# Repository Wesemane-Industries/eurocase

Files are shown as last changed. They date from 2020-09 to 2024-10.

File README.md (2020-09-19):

# Eurocase
DIY Eurorack / Modular synthesizer case by Wesemane Industries

## Overview
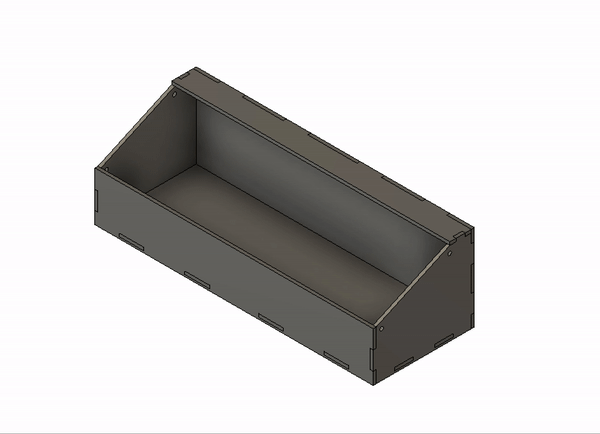
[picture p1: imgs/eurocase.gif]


## What you will need
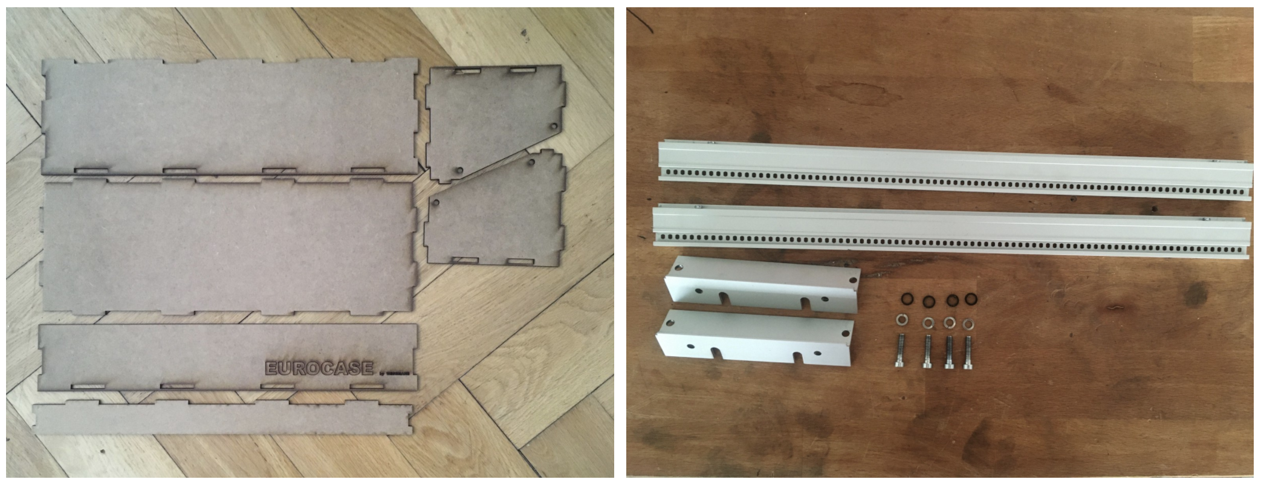
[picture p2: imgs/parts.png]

The left image shows all medium-density fibreboard (MDF) parts needed. You can either order them from my [Tindie shop](https://www.tindie.com/products/wesemane-industries/eurocase-by-wesemane-industries/) or laser cut them yourself (see DIY section below if you want to do so). <br>
The right image shows rails (including tapped strips), fixing brackets and all needed screws. You can get these parts from Schneidersladen following these links (Screws are included):<br>
* 2x [SB Rail 19"](https://schneidersladen.de/de/sb-rail-19-mit-kante)<br>
* 2x [Tapped strips 84TE (Gewindestreifen)](https://schneidersladen.de/de/gewindestreifen-84te) <br>
* 2x [Fixing bracket for 19"(Haltewinkel f. 19" BGT 3 HE)](https://schneidersladen.de/de/haltewinkel-f.-19-bgt-3-he)

## What it will look like in the end
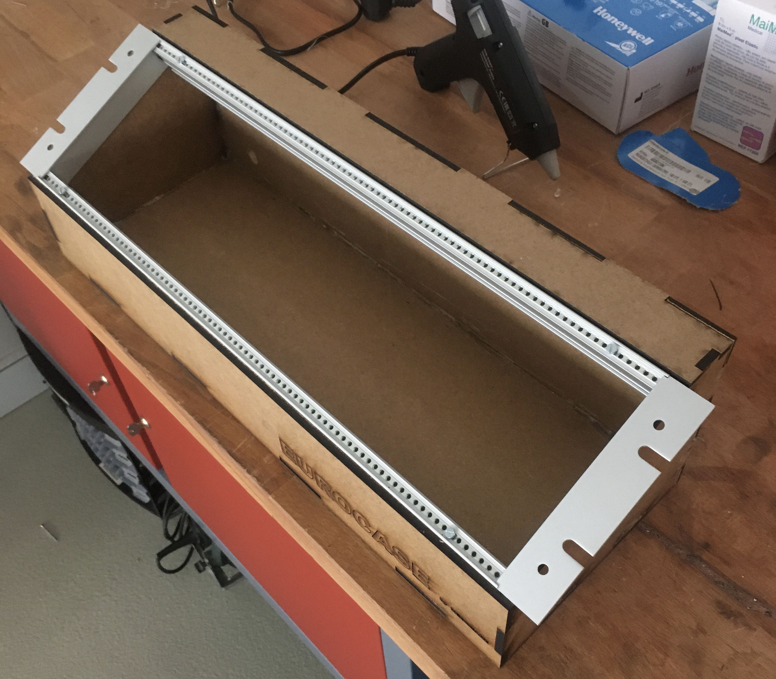
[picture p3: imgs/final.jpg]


## How to build
### Step 1 
Get all parts described above

### Step 2
Get a hot glue gun and hot glue all parts. I think it is self explanatory how to do that. <br>
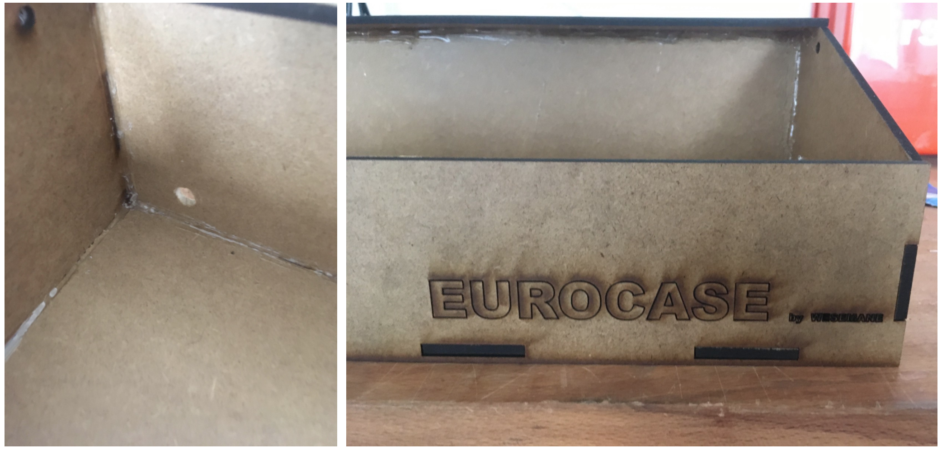
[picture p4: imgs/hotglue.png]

You should end up with a case that looks like this
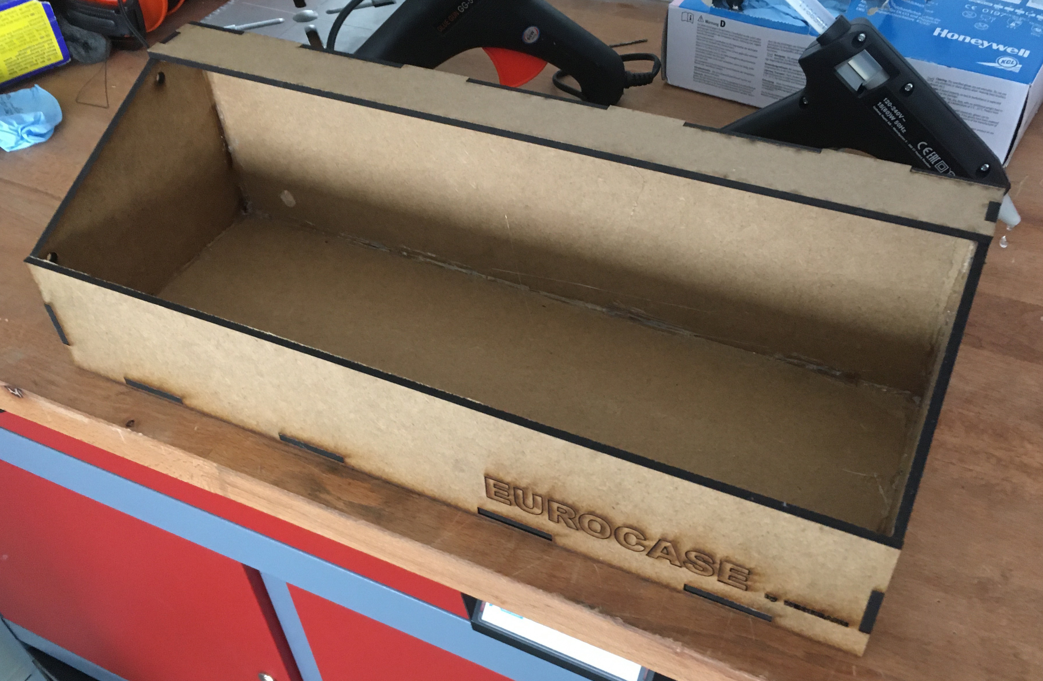
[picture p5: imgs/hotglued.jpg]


### Step 3
The 19" SB rails will be delivered including screws, but there will be no thread to hold the screws. You can use the screws to create the correct thread by just screwing them in. But make sure when you start to hold the screw perpendicular to the rail otherwise you will have issues later. The end result should look like this
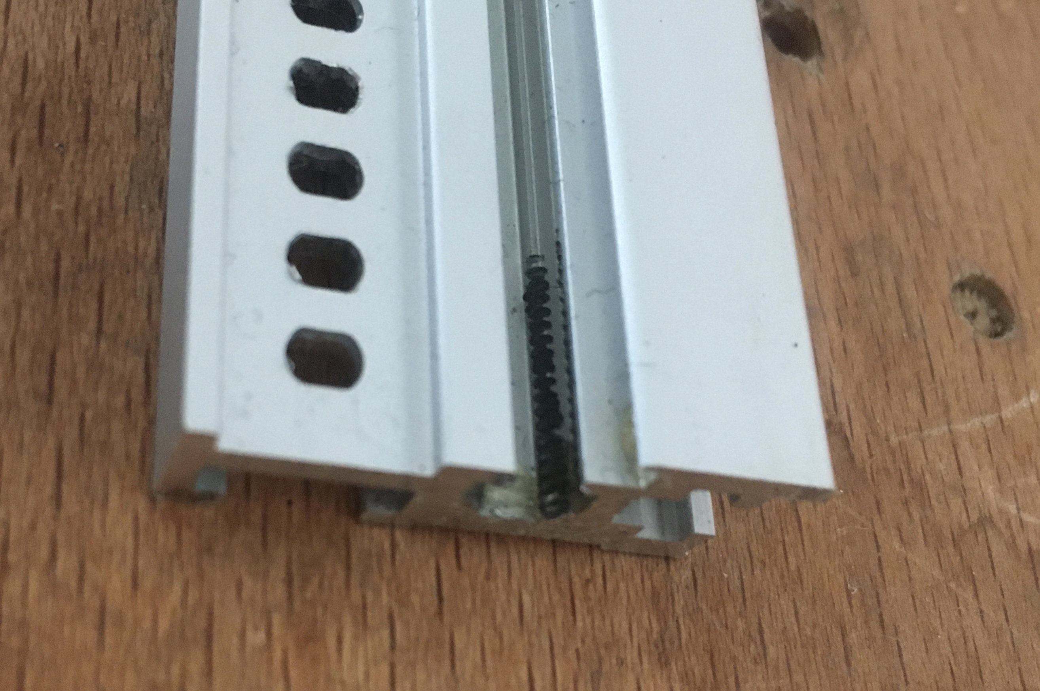
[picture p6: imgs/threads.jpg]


### Step 4
This step shows how to the fixing bracket is attached to the rail. The left image shows how you could optionally add a washer for stability, but it is not necessarily needed. Start by attaching the fixing bracket to the top left corner by using the designated drill hole in the case. Do not screw it in all the way just yet otherwise you could break it. Wait to finally fix it in the next Step.
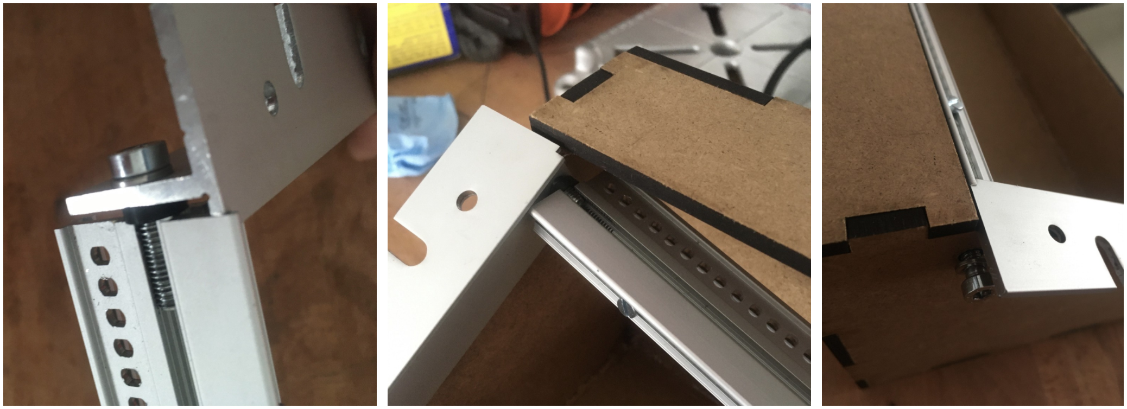
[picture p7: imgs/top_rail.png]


### Step 5
Next attach it to the opposite side and screw both sides in tightly.
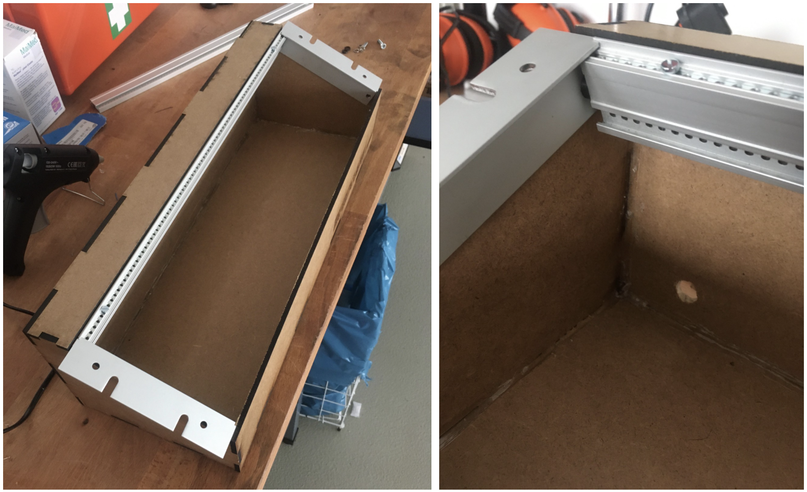
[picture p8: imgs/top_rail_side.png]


### Step 6
Do the same thing for the bottom row.
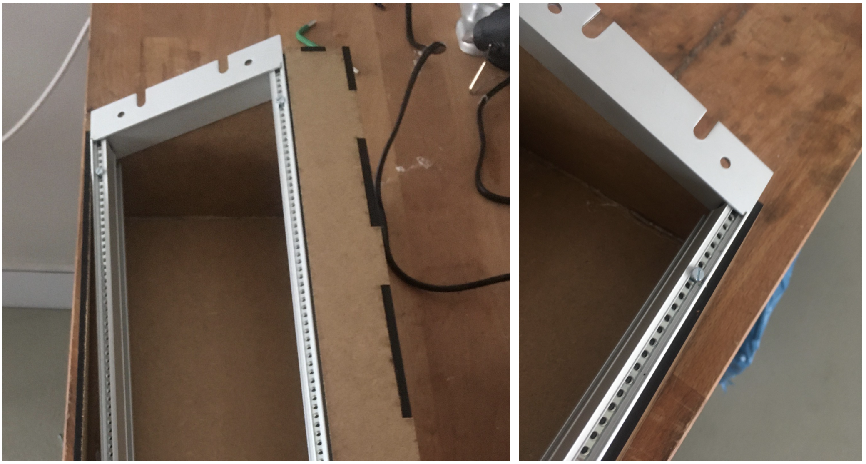
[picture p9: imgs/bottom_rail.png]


### Step 7
You are done! Your case should look like expected in the image above. Congrats enjoy your new Eurocase!

## DIY
You want to laser cut the case yourself? Navigate to [DIY](./DIY) folder and do it! You will find all files as *.dxf* and a fully prepared Illustrator *.ai* file.

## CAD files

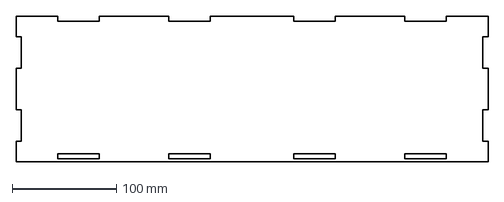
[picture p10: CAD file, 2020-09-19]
DIY/back.dxf
453.0 x 140.0 mm

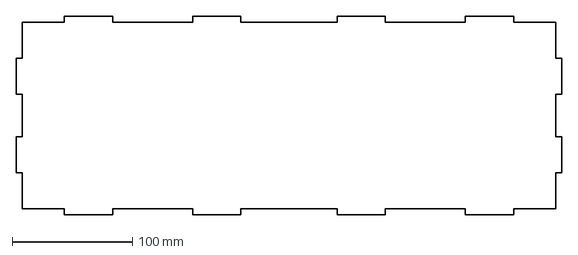
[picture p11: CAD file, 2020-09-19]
DIY/bottom.dxf
453.0 x 165.0 mm

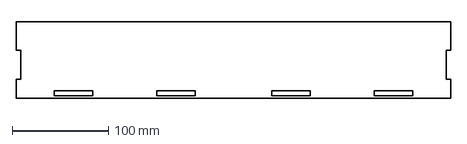
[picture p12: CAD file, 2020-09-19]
DIY/front.dxf
453.0 x 80.0 mm

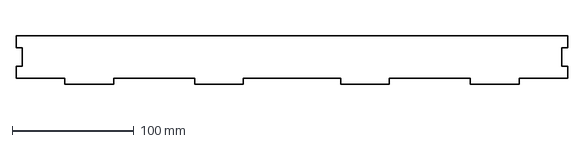
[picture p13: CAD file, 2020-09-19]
DIY/top.dxf
453.0 x 40.0 mm

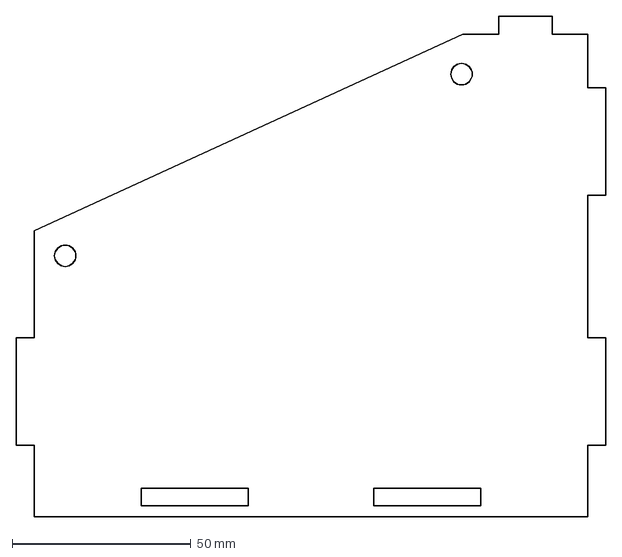
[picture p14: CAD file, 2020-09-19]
DIY/sides.dxf
165.0 x 140.0 mm

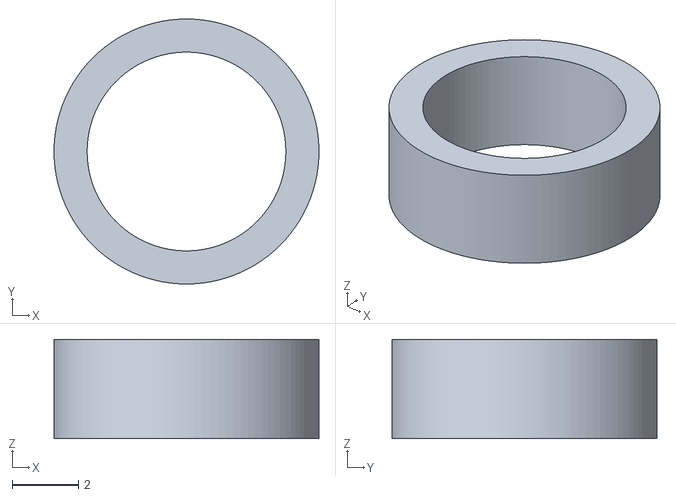
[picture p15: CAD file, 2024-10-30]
stl/washer.stl
8.00 x 8.00 x 3.00

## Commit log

2020-09-19 add assembly instructions and DIY files
    [back.dxf, bottom.dxf, front.dxf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]
2021-04-14 update illustrator ai file for laser cut
2024-10-29 add washer stl for 3d print
    [washer.stl]
2024-10-29 update files
    [washer.stl]
2024-10-30 update dimensions of washer
    [washer.stl]
